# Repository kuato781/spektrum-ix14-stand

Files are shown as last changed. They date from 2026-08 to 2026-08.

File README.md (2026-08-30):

# Adjustable Stand for the Spektrum iX14

A folding, indexed-position desk stand designed for the square carrying handle on the Spektrum iX14 transmitter.

The stand mounts without permanently modifying the radio, folds against the back for storage, and uses a spring-loaded ball plunger with a detent mechanism to provide repeatable viewing positions.

V2 introduces **SMUT™** — **S**ide **M**ount **U**nit **T**echnology: a reusable side-mounted architecture that places independent retained pivots on the individual handle rails instead of relying on a single rear-mounted clamp.

## Which Version Should I Build?

**Build V2 unless you specifically want to reproduce the original prototype.**

| Version | Status | Design | Recommendation |
|---|---|---|---|
| [V2](v2/) | Current design | SMUT™ side-mount assemblies with independent pivots and a replaceable detent ring | **Recommended** — more compact, easier to align, leaves more of the handle open, and is substantially more functional |
| [V1](v1/) | Legacy prototype | CRAP™ rear-mount platform with one external clamp and a common through-bolt pivot | Preserved for reference; development stopped after the concept was proven and moved to V2 |

V1 was successfully printed, assembled, and used as a prototype, but it occupies more handle space, has a taller folded profile, and is less convenient than V2.

It is not the version recommended for a new build.

## Product Photos

Photographs of the actual printed and assembled stands are included with each version:

- [V1 product images](v1/documentation/product-images/) show the original prototype as separate components, assembled, folded, and extended.
- [V2 product images](v2/documentation/product-images/) show the recommended design as separate components, assembled, folded, extended through its usable range, and installed with handle clearance. The V2 collection also includes a direct V1-versus-V2 extension comparison.

These are photographs of physical builds, not CAD renders. For installation order and hardware placement, use the version-specific assembly instructions and printable assembly guide.

## V2 — Recommended SMUT™ Build

V2 is the first physically validated implementation of SMUT™ and includes:

- independent left and right handle-mounted case assemblies;
- self-aligning clamp clearance for radio-to-radio manufacturing variation;
- separate retained pivots that remain free after their hardware is tightened;
- replaceable, keyed detent ring that can be printed as a contrasting wear item;
- square keyed blocks that carry stand shear and twisting loads;
- reinforced heat-set-insert collars;
- directional caps marked `L` and `R`;
- a 110 mm stand with paintable chamfers and editable multicolor text;
- PETG-HF print profiles and tested Bambu Studio plate arrangements.

### Why SMUT™?

**Because rear-entry solutions are unnecessarily restrictive.**

By moving the pivot assemblies to the individual handle rails, SMUT™ preserves full carrying-handle access while providing independent retained pivots, positive indexed positioning, greater range of motion, and a more compact folded profile.

### Start Here

- [V2 assembly instructions](v2/documentation/assembly-instructions/)
- [V2 printable assembly guide](v2/documentation/exploded-view/)
- [V2 Bambu Studio profile](v2/bambu-studio-3mf/)
- [V2 hardware buy list](v2/buy-list/)
- [V2 STL files](v2/stl/)

> **Validation status:** The complete V2 assembly has been physically validated on the radio, including the printed parts, inserts, clamp fit, pivots, stand interface, production M4 × 8 spring-loaded ball plunger, positive detent engagement, full range of motion, folded position, and carrier fit.

## V1 — Legacy CRAP™ Prototype

V1 remains available as the original implementation of **CRAP™** — **C**audal **R**ear **A**nchoring **P**latform — and the project's proof-of-concept design.

Its directory contains the printable models, Bambu Studio project, hardware list, and abbreviated assembly documentation needed to reproduce it.

- [V1 assembly instructions](v1/documentation/assembly-instructions/)
- [V1 printable assembly guide](v1/documentation/exploded-view/)
- [V1 hardware buy list](v1/buy-list/)
- [V1 STL files](v1/stl/)

V1 was prototyped in PLA using largely default Bambu settings.

No further V1 design development is planned; use V2 for the more practical final implementation.

In architectural terms, development moved from CRAP™ to SMUT™.

## AI-Assisted Design and Development

This project was developed with AI assistance.

The stand began with a practical design goal: create a compact, folding stand for the Spektrum iX14 that could mount to the existing square carrying handle without permanently modifying the transmitter.

AI was used throughout the iterative development process to help:

- analyze physical measurements and fitment observations;
- translate design requirements into 3D geometry;
- generate and revise printable models;
- evaluate clearances, interfaces, pivots, detent geometry, and hardware placement;
- create prototype variations based on physical test results;
- organize the versioned design artifacts;
- generate and maintain assembly documentation.

The development process was highly iterative:

**measure → model → print → physically test → revise**

The generated geometry was not assumed to be correct simply because it looked correct in CAD.

Multiple physical prototypes and fitment iterations were used to refine the design, and the repository distinguishes between the original V1 proof-of-concept and the more functional V2 design that resulted from that process.

In other words: AI helped design it, but the printer and the actual radio got the final vote. :-)

## Repository Organization

Each version is self-contained.

| Directory | Contents |
|---|---|
| `stl/` | Individual printable parts |
| `bambu-studio-3mf/` | Ready-to-slice Bambu Studio project and version-specific printing notes |
| `buy-list/` | Version-specific hardware requirements |
| `documentation/assembly-instructions/` | Detailed Markdown assembly instructions |
| `documentation/exploded-view/` | Printable PDF assembly guide and its linked page images |
| `documentation/product-images/` | Photographs of the actual printed parts and completed assembly |

Version-specific dimensions, hardware, slicer settings, and assembly procedures live inside the corresponding version directory so that the root README does not become another stale copy of those details.

## Important Safety Information

- This is a desk and simulator stand, **not a replacement carrying handle**.
- Inspect every print, insert, and fastener before use and periodically afterward.
- Confirm stability before placing the radio on an elevated, uneven, or windy surface.
- Never force the stand beyond its intended range of motion.
- Read the repository [`DISCLAIMER.md`](DISCLAIMER.md) before printing or using the design.

This is an independent project and is not affiliated with or endorsed by Horizon Hobby or Spektrum.

## License

This project is provided under the [Creative Commons Attribution-NonCommercial 4.0 International License](LICENSE).

You may print, copy, share, and modify the files for noncommercial purposes with attribution.

Changes must be identified.

The original files and derivatives may not be sold or otherwise used commercially without separate permission from the creator.

## Why?

Because apparently the natural progression of:

**RC helicopters + 3D printing + AI + excessive iteration**

is spending an unreasonable amount of time designing a stand for a radio that already has a handle.

And that's pretty kewl. :-D

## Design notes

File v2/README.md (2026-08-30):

# Spektrum iX14 Stand — V2 SMUT™ Recommended Design

V2 is the current and recommended stand design and the first physically validated implementation of **SMUT™** — **S**ide **M**ount **U**nit **T**echnology. Its two compact assemblies mount around the individual handle rails, preserving more usable handle space while providing independent retained pivots and a replaceable keyed detent ring.

## Why SMUT™?

**Because rear-entry solutions are unnecessarily restrictive.**

SMUT™ moves the stand pivots from a single rear-mounted clamp to purpose-designed side-mount assemblies. The result preserves full carrying-handle access while providing positive indexed positioning, greater range of motion, straightforward left-to-right alignment, and a more compact folded profile.

## Product Images

The [V2 product-images directory](documentation/product-images/) contains photographs of the actual printed and assembled design:

- a direct V1-versus-V2 extension comparison (`00-v1-vs-v2-range.jpg`);
- separate printed components;
- completed assembly;
- folded position;
- normal and maximum extended positions;
- side views showing the increased range of motion;
- remaining carrying-handle clearance.

These photographs document the physical build and its usable positions; they are not CAD renders or assembly diagrams.

## Version Contents

- [STL files](stl/)
- [Bambu Studio project and tested PETG-HF profile](bambu-studio-3mf/)
- [Hardware buy list](buy-list/)
- [Assembly instructions](documentation/assembly-instructions/)
- [Printable assembly guide](documentation/exploded-view/)

The complete V2 assembly has been physically validated on the radio, including the printed parts, inserts, clamp fit, pivots, stand interface, production M4 × 8 spring-loaded ball plunger, positive detent engagement, full range of motion, folded position, and carrier fit.

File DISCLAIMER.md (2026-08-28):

# Use at Your Own Risk

The design files, models, print profiles, instructions, photographs and other materials in this repository are provided for personal, noncommercial use on an **as-is** and **as-available** basis.

## No warranty

No warranty or representation is made that the materials are accurate, complete, error-free, safe, suitable for a particular purpose or compatible with any specific printer, material, tool, device or application.

3D-printed parts can vary significantly because of printer calibration, filament condition, material selection, slicer settings, print orientation, layer adhesion, environmental exposure, assembly technique, hardware tolerances and normal wear.

## Your responsibility

You are solely responsible for determining whether a design is suitable for your intended use. Before relying on any printed part or procedure, you should:

- Review the design, dimensions, hardware and instructions.
- Confirm that your printer, material and slicer settings are appropriate.
- Inspect every print for cracks, poor layer adhesion, deformation or other defects.
- Verify the fit, alignment, fasteners, inserts and range of motion during assembly.
- Test the completed item in a controlled and safe environment.
- Reinspect printed parts and hardware periodically and replace anything damaged, loose or worn.
- Independently verify any measurements, alignments, control settings or mechanical adjustments that could affect equipment operation or safety.

Do not assume that a successful print or another user's successful result guarantees that your copy will perform the same way.

## Assumption of risk

By downloading, printing, modifying, assembling or using these materials, you accept all associated risks. These may include failed prints, damaged filament or tools, ruined project materials, damage to equipment or property, loss of use and personal injury.

These materials are not professionally engineered, certified or tested as safety equipment. Do not use them for life-support, fall-protection, structural, load-bearing, emergency or other safety-critical applications.

## Limitation of liability

To the maximum extent permitted by applicable law, the creator and contributors will not be liable for any direct, indirect, incidental, special, consequential, exemplary or other loss, damage, cost or injury arising from the materials or their use, modification, assembly or inability to be used.

## Modifications and redistribution

If you modify or redistribute these materials, clearly identify your changes. You are responsible for validating your modified version and should preserve this disclaimer or provide an equivalent notice to downstream users.

## Relationship to the license

This disclaimer supplements the repository's [`LICENSE`](LICENSE) file and does not replace or modify its terms. If there is any conflict, the license controls.

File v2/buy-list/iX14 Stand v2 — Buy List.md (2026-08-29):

# iX14 Stand v2 — Buy List

### Heated inserts
- [ ] **6 × M3 heat-set inserts**, approximately **5 mm OD × 5 mm long** 
- [ ] **1 × M4 heat-set insert**, approximately **6 mm OD × 6 mm long** 
### Ball plunger
- [ ] **1 × M4 × 0.7 spring-loaded ball plunger**
  - Approximately **8–9 mm overall threaded-body length**
  - Approximately **2.5 mm ball**
  - Tested hardware elastic range: **3–15 N**
  - Available at Lowes: <a href="https://www.lowes.com/pd/Unique-Bargains-Ball-Point-Set-Screws-M4-x-8mm-304-Stainless-Steel-Metric-Spring-Hex-Socket-Screw-20pcs/6374188" target="_blank" rel="noopener noreferrer">M4 x 8mm Spring Hex Socket Screw</a> *(Ctrl+Click or Cmd+Click to open in a new tab)*
## Bolts, washers, nuts
- [ ] **2 × M4 × 20 mm socket-head or button-head screws**
- [ ] **2 × M4 nyloc nut**
- [ ] **2 × M4 flat washers**
- [ ] **4 × M3 × 12 mm socket-head or button-head screws**
- [ ] **2 × M3 × 8 mm socket-head or button-head screws**
- [ ] **2 × M3 flat washers**

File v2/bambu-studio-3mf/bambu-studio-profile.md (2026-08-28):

# Bambu Studio Profile — iX14 Stand V2

The supplied Bambu Studio project contains all eight V2 printed parts arranged across four plates:

[`../bambu-studio-3mf/ix14_v2_stand_all_objects.3mf`](../bambu-studio-3mf/ix14_v2_stand_all_objects.3mf)

The project was prepared on a Bambu Lab H2C with an AMS HT and two AMS 2 Pro units. It may be adapted to another compatible Bambu printer, but always confirm the printer, plate, nozzle and filament assignments before slicing.

## Recommended material

- Bambu PETG-HF for all structural parts
- Dry PETG-HF at 65 °C for eight hours before printing
- Use the built-in **Bambu PETG HF** filament preset
- Textured PEI build plate

## Global process settings

Start with **0.20 mm Standard** and change only the following:

- 0.4 mm standard nozzle
- 5 wall loops
- 5 top shell layers
- 5 bottom shell layers
- 25% gyroid infill
- Standard speed
- No scaling or XY/hole compensation
- No ironing

## Four-plate project

| Plate | Contents | Notes |
| ---: | --- | --- |
| 1 | Both case bodies, both caps and both pivot stubs | Structural parts with per-object supports and the saved Auto brim setting |
| 2 | Replaceable detent ring | Print the detent pockets against the build plate |
| 3 | Single-color stand | No supports or brim |
| 4 | Multicolor stand with editable `LAWN-DART` text | Verify filament mapping, painted chamfers and text before slicing |

Only the filament slots used by the selected plate matter. The stored project uses Bambu PETG-HF for the active objects; unused AMS slots may still display other materials. Remap every active object to the intended PETG-HF spool before printing.

## Per-object settings

| Part | Orientation | Supports | Brim |
| --- | --- | --- | --- |
| Left and right case bodies | Supplied STL orientation | Tree (Auto), default style, build plate only | Auto brim, 5 mm width |
| Right detent pivot stub | Supplied STL orientation | Tree (Auto), default style, build plate only | Auto brim, 5 mm width |
| Left plain pivot stub | Lay on its side as arranged in the 3MF | Tree (Auto), default style, build plate only | Auto brim, 5 mm width |
| Left and right caps | Flip 180° so the joiner/mating face is on the build plate | None | Saved Auto setting; no manual brim required |
| Replaceable detent ring | Flat with detent pockets downward | None | None |
| Stand | Flat with sockets upward; rotate 90° on the build plate for improved torsional layer orientation | None | None |

> **Validated Plate 1 brim setting:** the global **Auto brim / 5 mm** setting stored in the 3MF completed a successful physical print of the full plate. Leave this setting as saved; no per-object 8 mm override is required.

## Multicolor stand

Plate 4 contains the paintable stand and an editable Bambu Studio text object.

1. Assign the stand body to the primary PETG-HF color.
2. Use the paint-bucket tool to fill the continuous chamfer faces with the accent color.
3. Edit or remove the `LAWN-DART` text as desired.
4. Assign the text to the accent-color PETG-HF spool.
5. Slice and inspect Preview to confirm that every intended chamfer and letter changes color cleanly.

Suggested color combinations:

- Deadpool: black body with red chamfers, text and detent ring
- Wolverine: black body with yellow chamfers, text and detent ring

## Pre-print checklist

- PETG-HF completed an eight-hour drying cycle
- Correct printer and textured PEI plate selected
- 0.4 mm nozzle selected
- Every active object mapped to PETG-HF
- Plate 1 retains the validated Auto brim / 5 mm setting
- Supports are build-plate-only on the four supported objects
- Detent ring pockets face downward
- Caps have their mating faces on the plate
- Stand sockets face upward
- Painted stand preview shows the intended colors
- First layers observed before leaving the printer unattended

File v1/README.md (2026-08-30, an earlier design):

# Spektrum iX14 Stand — V1 Legacy CRAP™ Prototype

V1 is the original implementation of **CRAP™** — **C**audal **R**ear **A**nchoring **P**latform — and the project's proof-of-concept stand. It was successfully printed, assembled, and used to validate the folding detent concept, but development moved to the more compact and functional [V2 SMUT™ design](../v2/).

Build V1 only if you specifically want to reproduce the original prototype. For a new stand, V2 is recommended.

## Product Images

The [V1 product-images directory](documentation/product-images/) contains photographs of the actual printed prototype:

- separate printed components;
- completed assembly;
- folded position;
- extended position;
- extended side view.

These photographs document the physical build and its usable positions; they are not CAD renders or assembly diagrams.

## Version Contents

- [STL files](stl/)
- [Bambu Studio project](bambu-studio-3mf/)
- [Hardware buy list](buy-list/)
- [Assembly instructions](documentation/assembly-instructions/)
- [Printable assembly guide](documentation/exploded-view/)

V1 was prototyped in PLA using largely default Bambu Studio settings. Its complete folding and indexed-detent mechanism has been physically validated with the production M4 × 8 spring-loaded ball plunger. No further V1 design development is planned.

In architectural terms, development moved from CRAP™ to SMUT™.

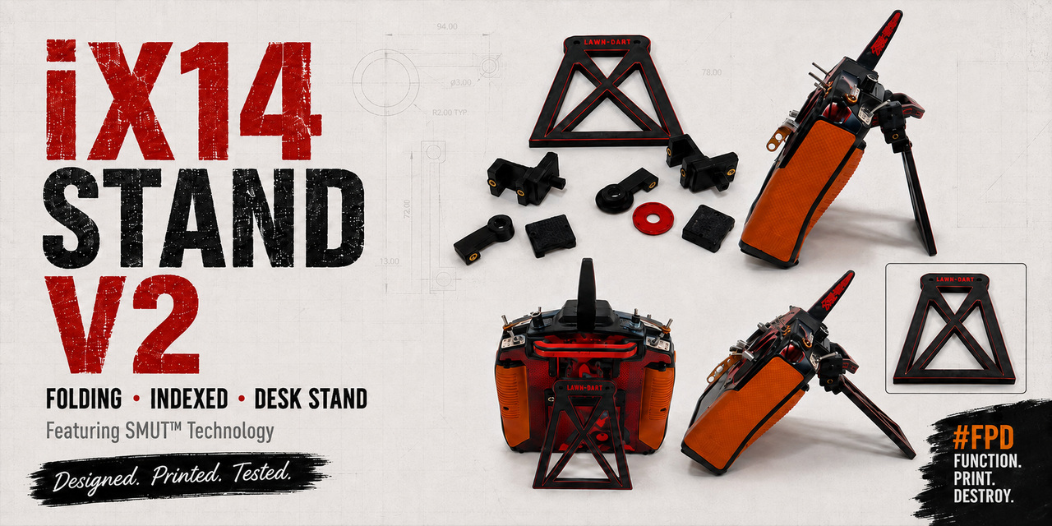
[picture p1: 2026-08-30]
ix14_stand_github_social_1280x640.jpg

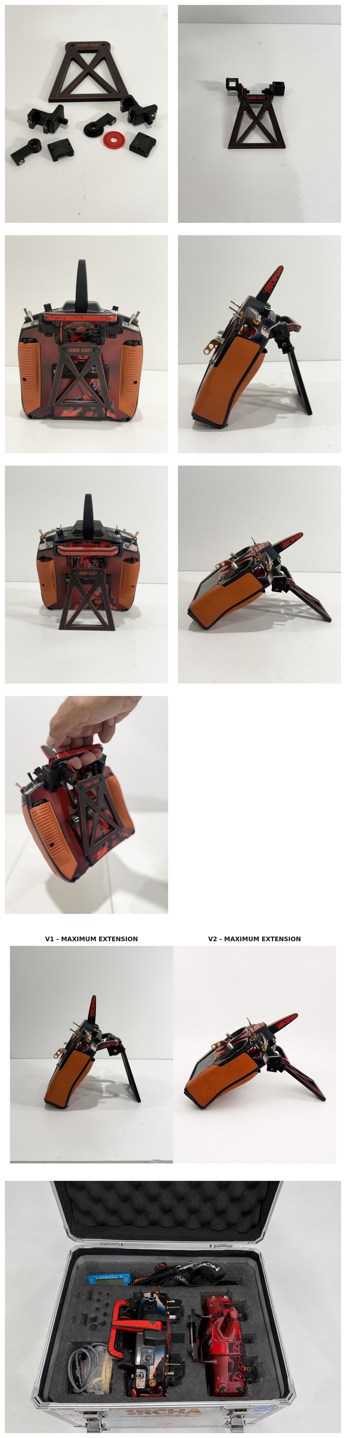
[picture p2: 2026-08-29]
v2/documentation/product-images/00-v2-contact-sheet.jpg

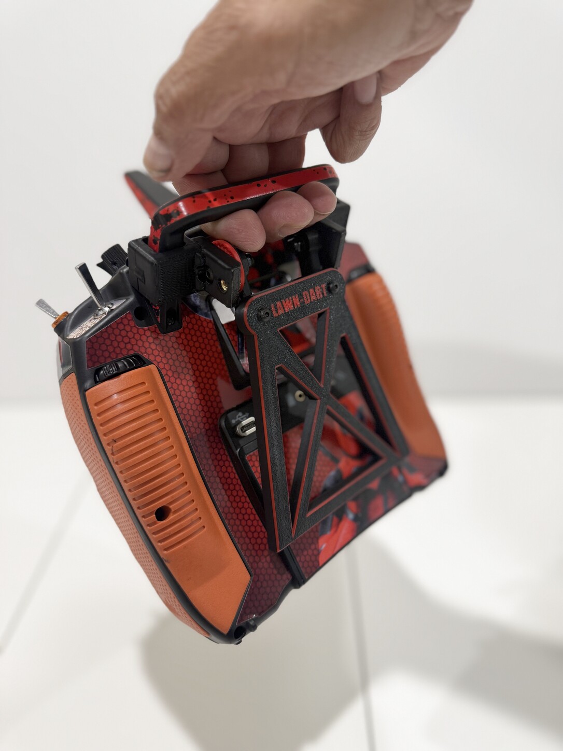
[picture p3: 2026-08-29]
v2/documentation/product-images/08-v2_clearance.jpg

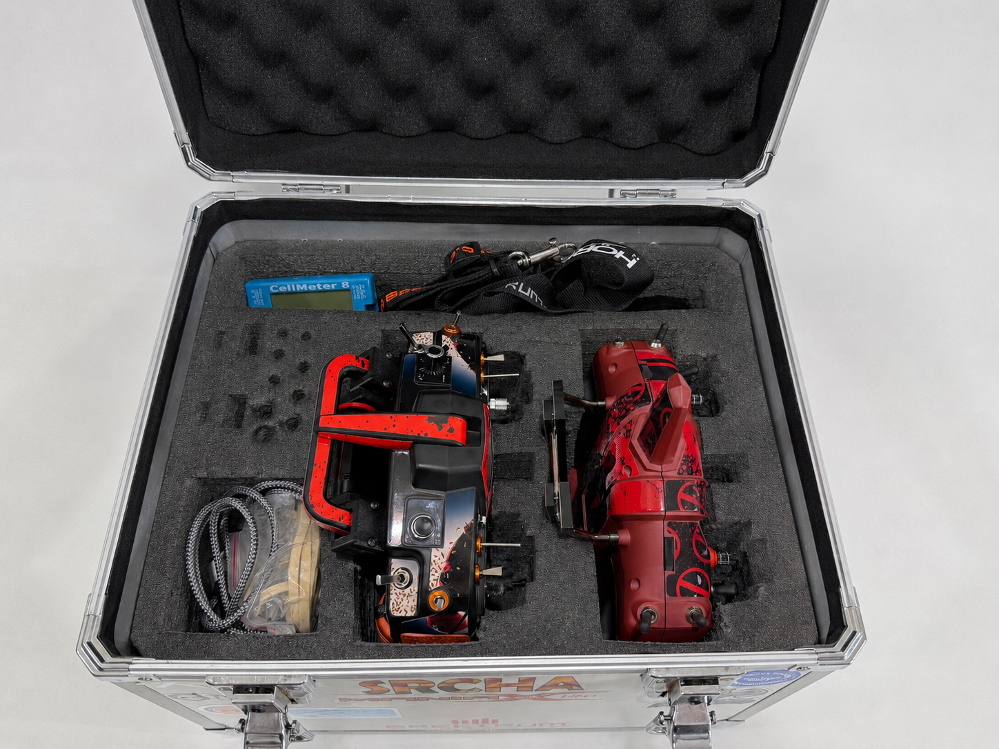
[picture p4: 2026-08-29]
v2/documentation/product-images/10-v2-carrier-fit.jpg

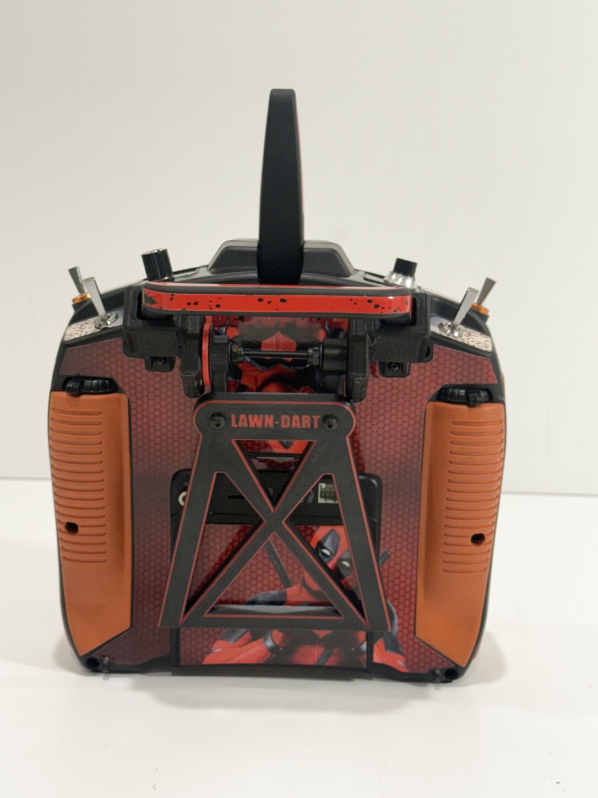
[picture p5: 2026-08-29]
v2/documentation/product-images/03-v2_folded.jpg

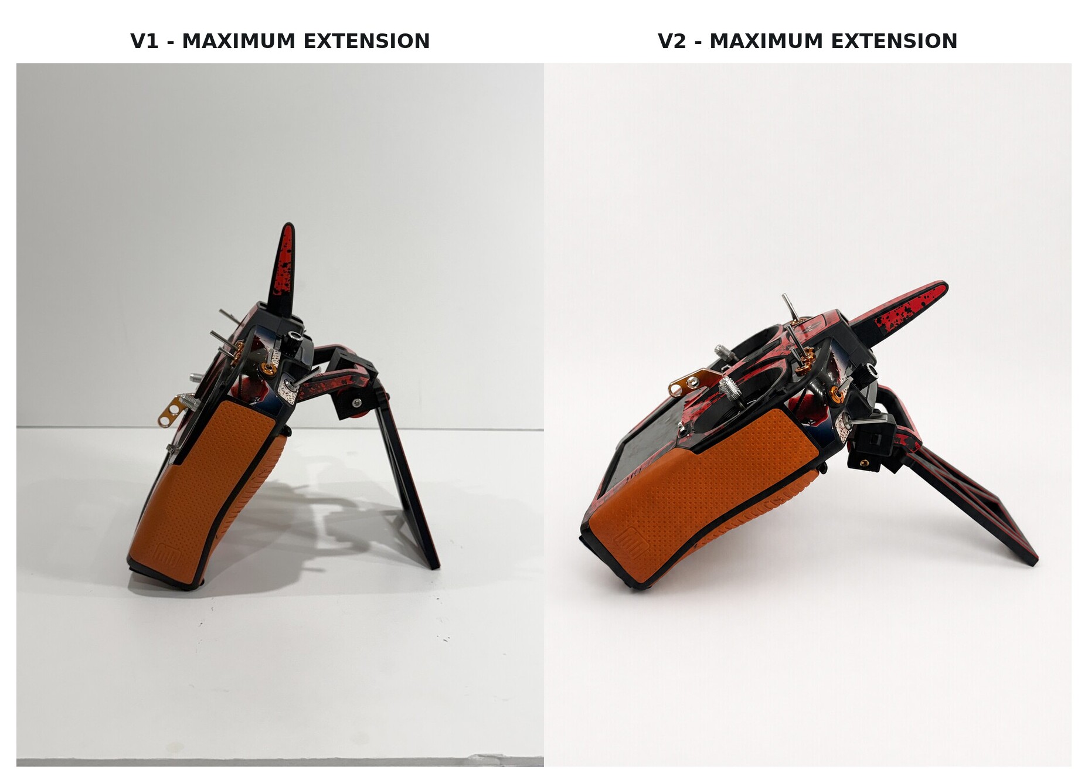
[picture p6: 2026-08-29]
v2/documentation/product-images/09-v1-vs-v2-range.jpg

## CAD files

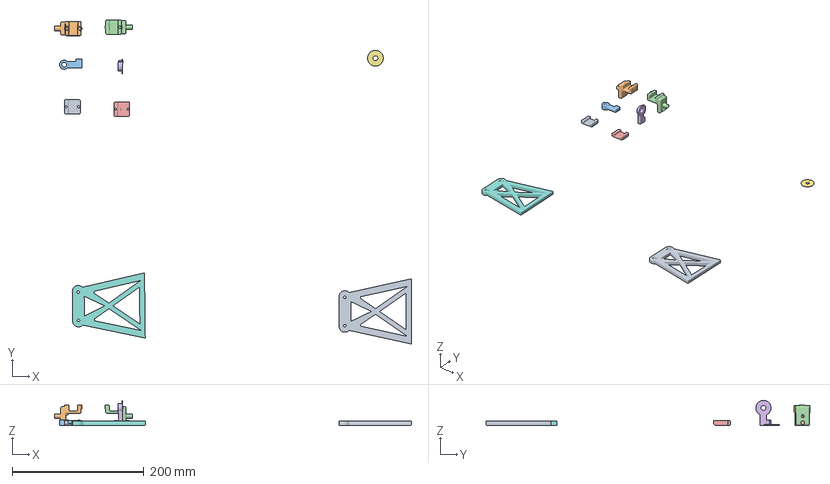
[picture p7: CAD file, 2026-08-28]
v2/bambu-studio-3mf/ix14_v2_stand_all_objects.3mf
541.7 x 491.7 x 38.5 mm
ix14_v2_left_case_cap.stl
ix14_v2_left_plain_case_body.stl
ix14_v2_left_plain_pivot_stub.stl
ix14_v2_right_detent_case_body.stl
ix14_v2_right_case_cap.stl
ix14_v2_right_detent_pivot_stub.stl
ix14_v2_replaceable_detent_ring.stl
ix14_v2_stand.stl
ix14_v2_stand_colored.stl

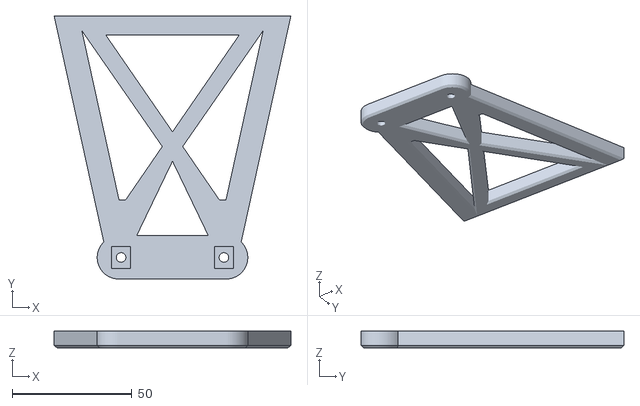
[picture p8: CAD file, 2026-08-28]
v2/stl/ix14_v2_stand.stl
99.0 x 110.0 x 7.00

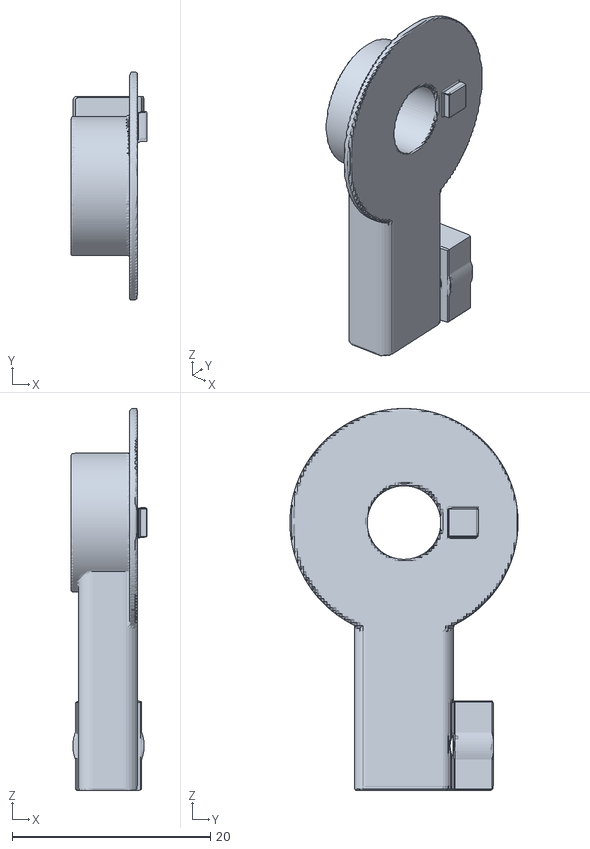
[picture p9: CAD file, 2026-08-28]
v2/stl/ix14_v2_right_detent_pivot_stub.stl
7.70 x 23.0 x 38.5

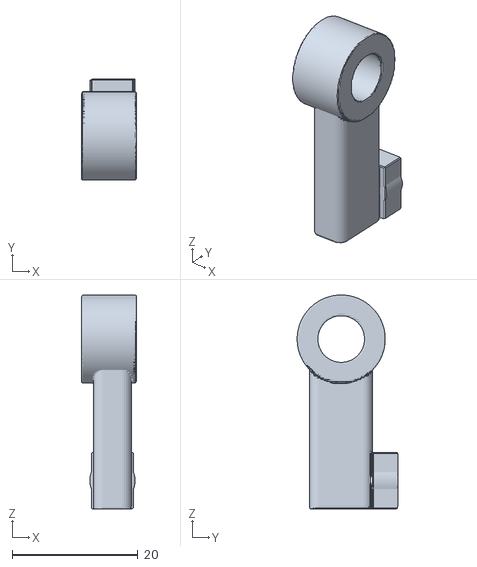
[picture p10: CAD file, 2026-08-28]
v2/stl/ix14_v2_left_plain_pivot_stub.stl
8.70 x 16.0 x 34.0

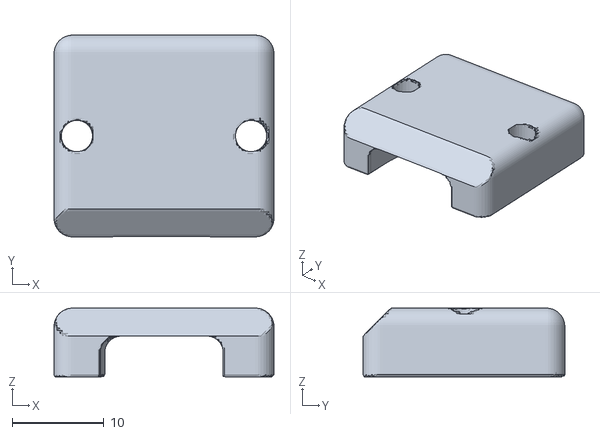
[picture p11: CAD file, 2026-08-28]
v2/stl/ix14_v2_left_case_cap.stl
24.0 x 22.0 x 7.50

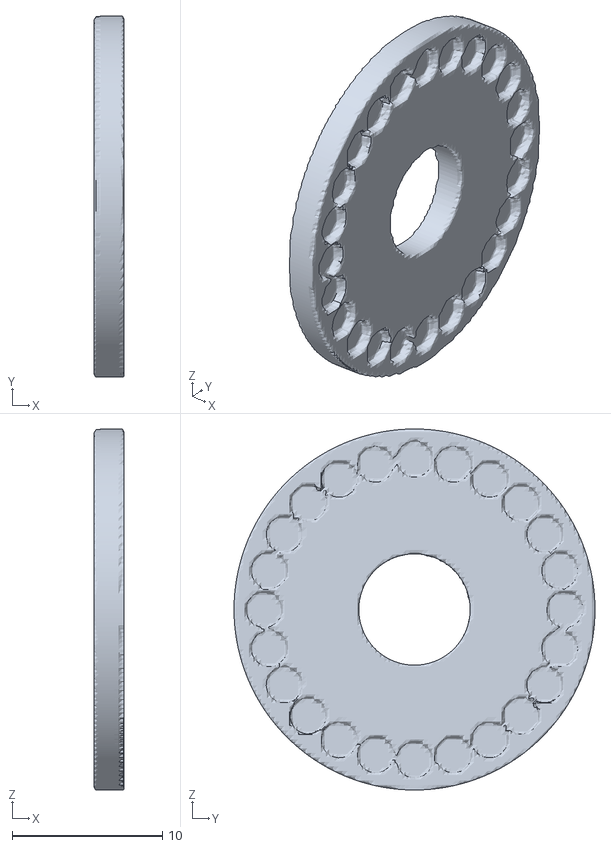
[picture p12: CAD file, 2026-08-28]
v2/stl/ix14_v2_replaceable_detent_ring.stl
2.00 x 24.0 x 24.0

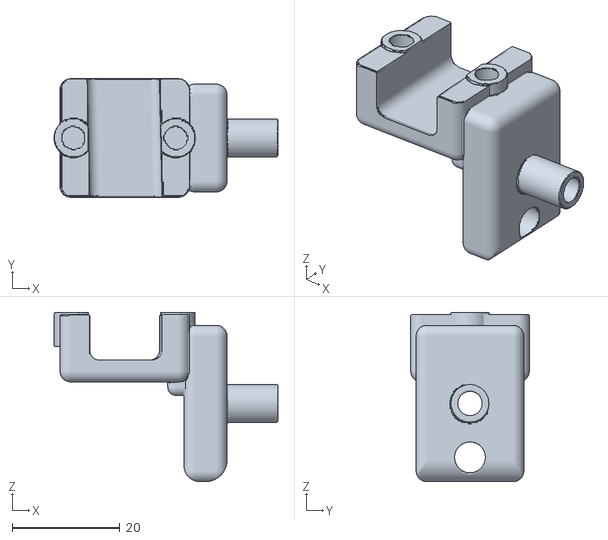
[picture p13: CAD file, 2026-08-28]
v2/stl/ix14_v2_right_detent_case_body.stl
41.5 x 22.0 x 31.4

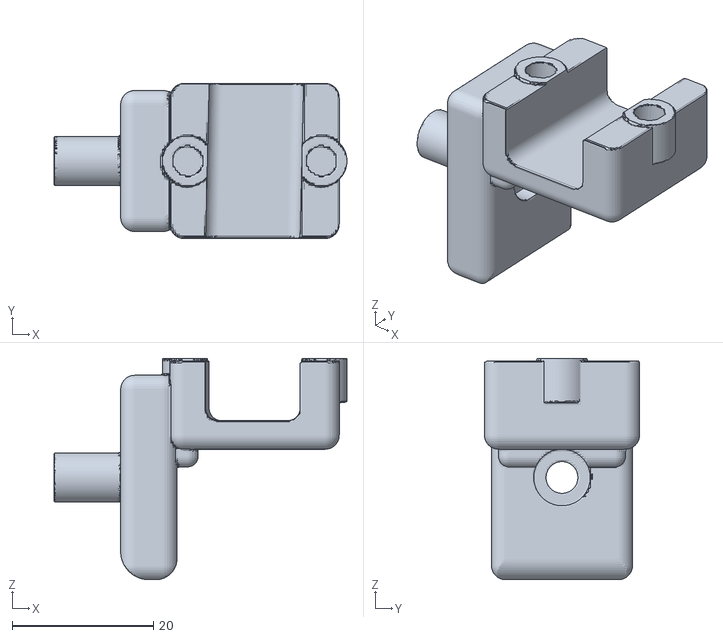
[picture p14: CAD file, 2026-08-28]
v2/stl/ix14_v2_left_plain_case_body.stl
41.5 x 22.0 x 31.4

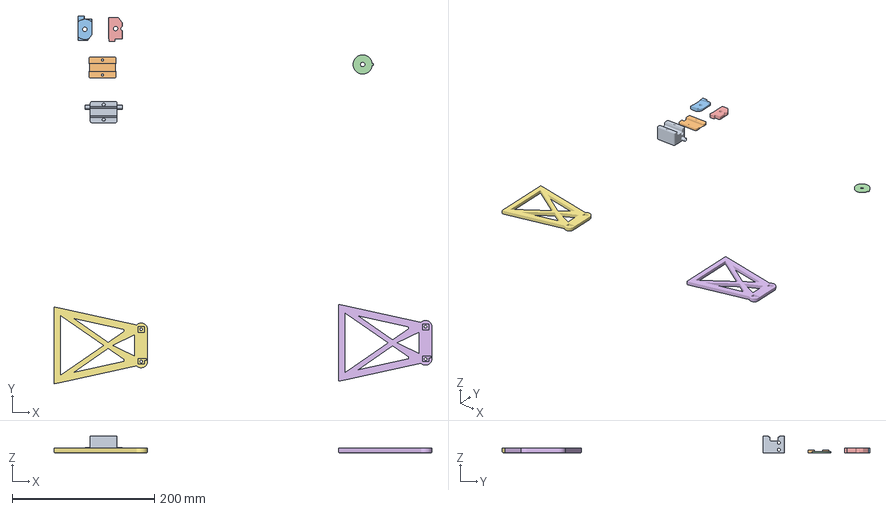
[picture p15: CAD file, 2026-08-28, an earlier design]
v1/bambu-studio-3mf/ix14_v1_stand_all_objects.3mf
531.1 x 516.6 x 23.5 mm
ix14_v1_clamp_body.stl
ix14_v1_clamp_cap.stl
ix14_v1_right_detent_ear.stl
ix14_v1_detent.stl
ix14_v1_left_ear.stl
ix14stand_v1.stl x 2

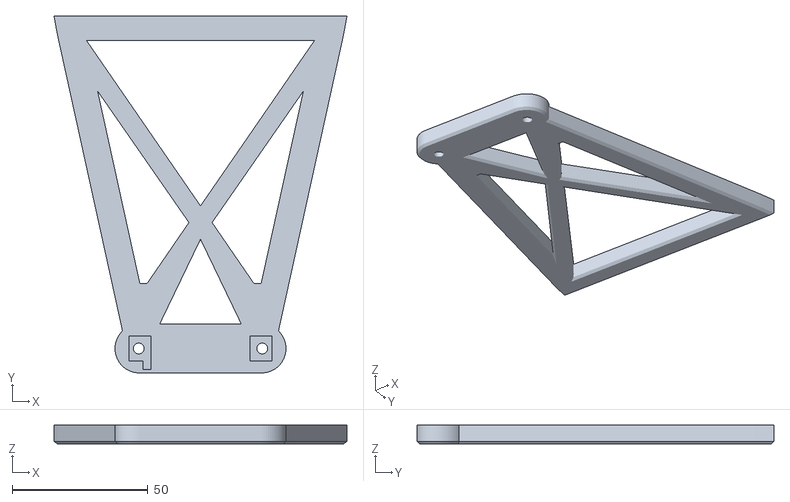
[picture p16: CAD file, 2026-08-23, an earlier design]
v1/stl/ix14_v1_stand.stl
107.9 x 131.5 x 7.00

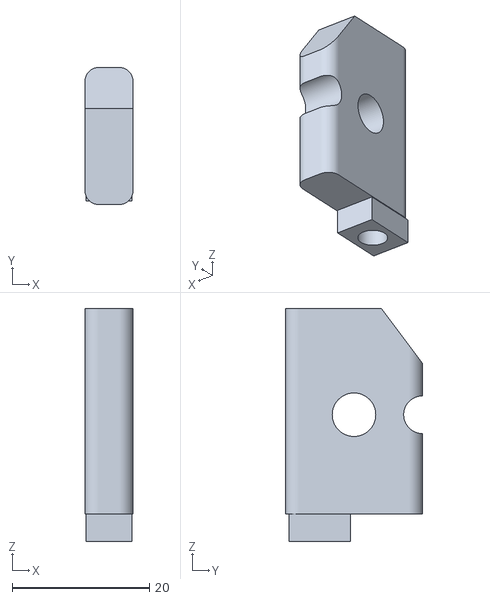
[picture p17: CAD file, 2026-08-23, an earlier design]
v1/stl/ix14_v1_left_ear.stl
7.00 x 20.0 x 34.0

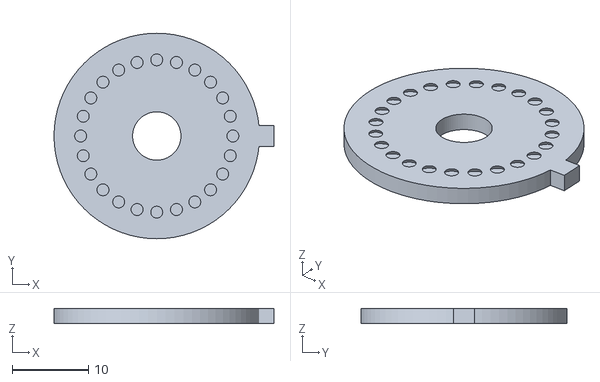
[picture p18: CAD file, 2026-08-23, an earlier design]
v1/stl/ix14_v1_detent.stl
28.9 x 27.0 x 2.00

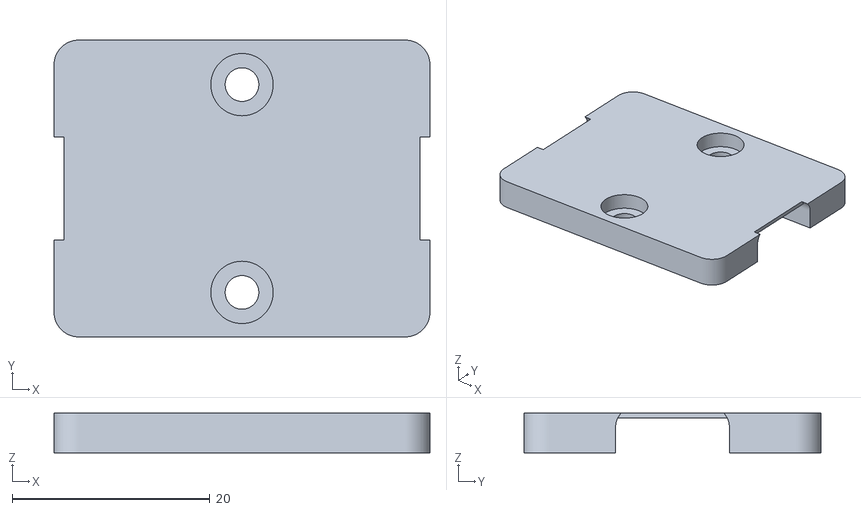
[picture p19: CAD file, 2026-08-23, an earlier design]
v1/stl/ix14_v1_clamp_cap.stl
38.0 x 30.0 x 4.00

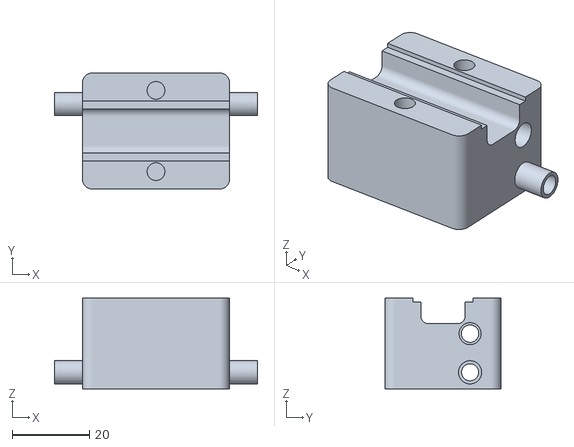
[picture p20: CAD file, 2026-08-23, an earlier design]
v1/stl/ix14_v1_clamp_body.stl
52.5 x 30.0 x 23.5

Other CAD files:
v2/stl/ix14_v2_right_case_cap.stl
v1/stl/ix14_v1_right_detent_ear.stl

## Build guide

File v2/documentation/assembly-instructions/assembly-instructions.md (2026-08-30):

# Assembly Instructions — iX14 Stand V2 SMUT™ System

[Download the printable three-stage assembly guide (PDF)](../exploded-view/ix14-v2-assembly-guide.pdf)

These instructions apply to the V2 implementation of **SMUT™** — **S**ide **M**ount **U**nit **T**echnology. Its independent left and right assemblies mount around the individual handle rails. **Left and right are always described while looking at the front of the radio.**

> **Hardware status:** the complete mechanism has been physically validated on the radio with the production M4 × 8 spring-loaded ball plunger. The plunger provides positive engagement at each indexed stand position while preserving smooth movement through the full range of motion.

## Printed parts

| Quantity | Part |
| ---: | --- |
| 1 | Left plain case body |
| 1 | Left cap, marked `L` underneath |
| 1 | Left plain pivot stub |
| 1 | Right detent case body |
| 1 | Right cap, marked `R` underneath |
| 1 | Right detent pivot stub |
| 1 | Replaceable detent ring |
| 1 | 110 mm stand |

Use the [V2 buy list](<../../buy-list/iX14 Stand v2 — Buy List.md>) for the complete hardware list.

## Insert locations

Install all heat-set inserts before mounting the cases to the radio.

- **4 × M3 inserts:** two reinforced cap-screw pockets in each case body
- **2 × M3 inserts:** one square stand-mounting block on each pivot stub
- **1 × M4 insert:** spring-plunger bore in the right detent case body

Use the alignment feature supplied with your heat-set tool, such as an insert-centering nub, whenever one is available. If your heat-set setup does not already provide an alignment solution, an appropriate screw may be threaded loosely into the insert to help keep it straight. Press the insert into its reinforced collar and allow the part to cool completely before applying load.

[Stage 1: build the left and right pivot assemblies](../exploded-view/images/step-1.png)

## 1. Assemble the right detent pivot

1. Place the replaceable detent ring on the support face of the right detent pivot stub.
2. Align the asymmetric square key and recess. The ring should seat fully without force.
3. Orient the detent pockets toward the right case body and its ball-plunger bore.
4. Slide the right pivot stub over the case body's 7 mm pivot sleeve.
5. Install the M4 pivot bolt through the case body, sleeve and stub.
6. Fit the M4 washer on the Nyloc side, then install the M4 Nyloc nut.
7. Tighten until the hardware is firmly seated. Confirm that the sleeve shoulder prevents the stub from being pinched and that the stub still rotates freely.

## 2. Assemble the left plain pivot

1. Slide the left plain pivot stub over the left case body's pivot sleeve.
2. Install the M4 pivot bolt through the case body, sleeve and stub.
3. Fit the M4 washer on the Nyloc side, then install the M4 Nyloc nut.
4. Tighten until firmly seated and confirm smooth, free rotation.

## 3. Mount the case assemblies to the handle

[Stage 2: attach the case assemblies to the radio handle](../exploded-view/images/step-2.png)

1. Place the completed left and right assemblies around their corresponding iX14 handle rails.
2. Match the cap marked `L` to the left body and the cap marked `R` to the right body.
3. Install two M3 × 12 screws through each cap.
4. Tighten the four cap screws only enough to hold the assemblies in place. Leave enough movement for the stand to square and align both sides.

Washers are not required under the case-cap screws.

## 4. Attach the stand

[Stage 3: attach, square and tighten the stand](../exploded-view/images/step-3.png)

1. Align the stand's two rectangular sockets with the square mounting blocks on the pivot stubs.
2. Seat both blocks completely in the stand sockets.
3. Install one M3 × 8 screw and M3 washer through each stand hole and into the insert in the corresponding stub block.
4. Leave both stand screws slightly loose during alignment.

The square blocks carry the stand's shear and twisting loads; the M3 screws retain and clamp the keyed connection.

## 5. Square and tighten the assembly

1. Push both handle-mounted case assemblies as far toward the radio body as they will naturally seat.
2. Use the attached stand to bring both pivot assemblies square and parallel.
3. Tighten the four M3 × 12 cap screws evenly, alternating between screws so each cap clamps uniformly.
4. Tighten the two M3 × 8 stand screws and washers.
5. Fold and deploy the stand through its complete travel to confirm that neither side binds or shifts.

Do not overtighten the cap screws against the radio handle.

## 6. Install and adjust the ball plunger

1. Use something thin, such as an awl or straightened paper clip, to place a **small amount of removable, non-permanent threadlocker** (for example, blue Loctite) inside the receiving threads of the M4 insert. Keep the threadlocker off the surrounding plastic and out of the plunger mechanism.
2. Insert the M4 × 8 spring-loaded ball plunger **ball end first** through the access bore, then thread it into the M4 insert in the right detent case body.
3. Advance the plunger a little at a time while repeatedly moving the stand between its fully folded and fully extended positions.
4. Continue making small adjustments until the ball engages the detent recesses solidly at each indexed position without making the pivot overly tight or difficult to move.
5. Cycle the stand repeatedly through its full range. Confirm positive engagement at every position and verify that the replaceable detent ring remains fully seated.

The correct setting is the point at which the detents feel deliberate and secure while the stand still moves smoothly. Do not use permanent threadlocker.

## Final inspection

- Both case assemblies are fully seated toward the radio body
- Left and right caps are correctly matched
- All four cap screws are evenly tightened
- Both pivot bolts are secure with washers and Nyloc nuts
- Both pivots rotate freely without axial looseness
- Detent ring key is fully seated and pockets face the plunger
- Ball plunger engages each detent recess positively without binding
- Stand blocks are fully seated in both sockets
- Both stand screws have washers and are secure
- Stand deploys smoothly and supports the radio at the intended angle
- Stand folds without contacting the radio body, switches or controls
- Handle opening remains clear for normal carrying

## Safety and maintenance

- This is a desk/simulator stand, not a replacement carrying handle.
- Inspect the printed parts, inserts and fasteners periodically for cracks, loosening or wear.
- Replace the detent ring if its pockets become rounded or inconsistent.
- Recheck cap and stand screws after the first several use cycles.
- Recheck the ball-plunger adjustment after the first several use cycles and whenever engagement begins to feel weak or excessively tight.
- Never force the stand beyond its designed range of motion.
- Use the stand at your own risk and verify stability before placing the radio on any elevated, uneven or windy surface.

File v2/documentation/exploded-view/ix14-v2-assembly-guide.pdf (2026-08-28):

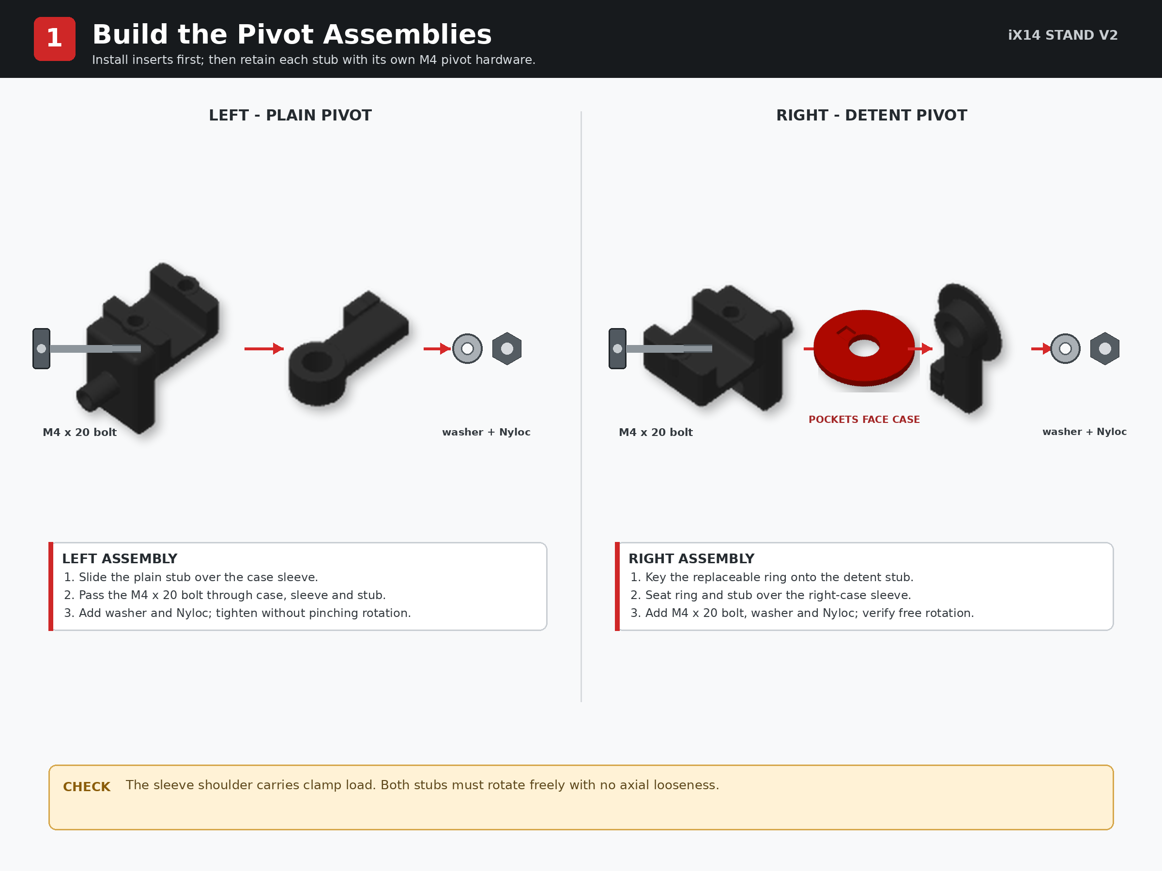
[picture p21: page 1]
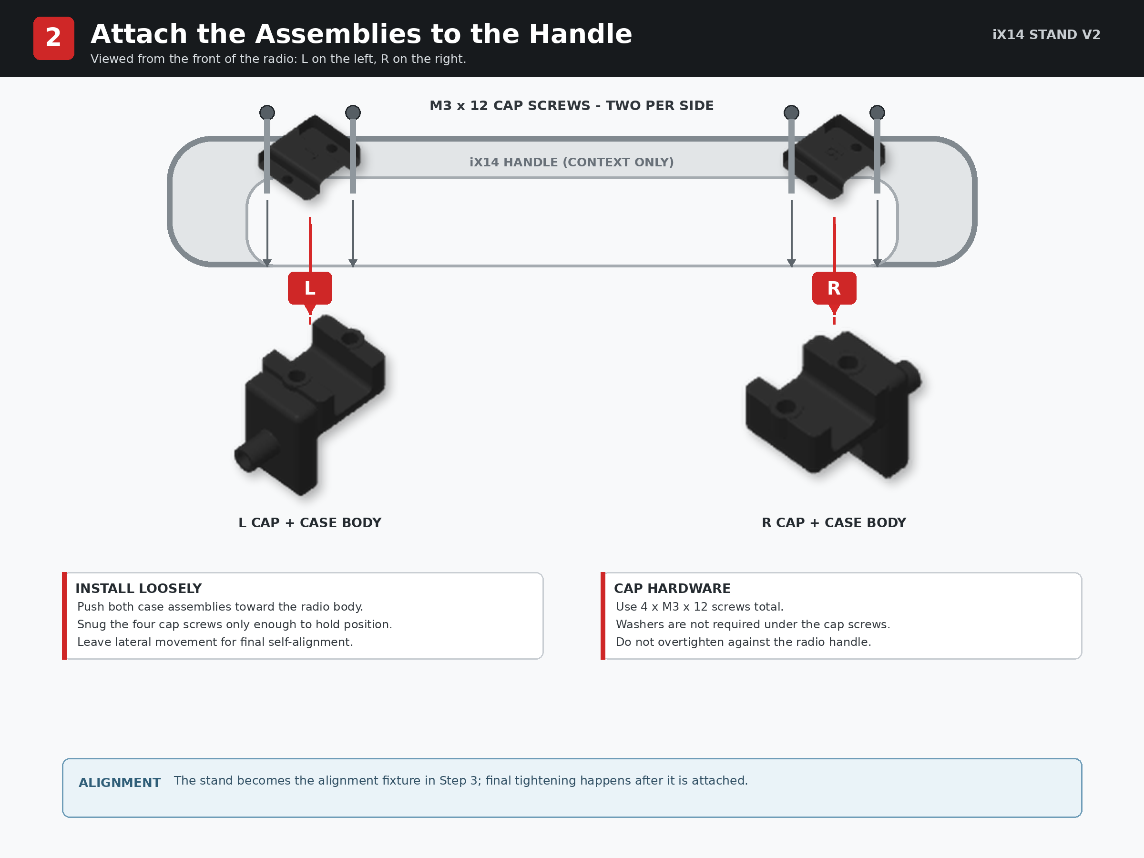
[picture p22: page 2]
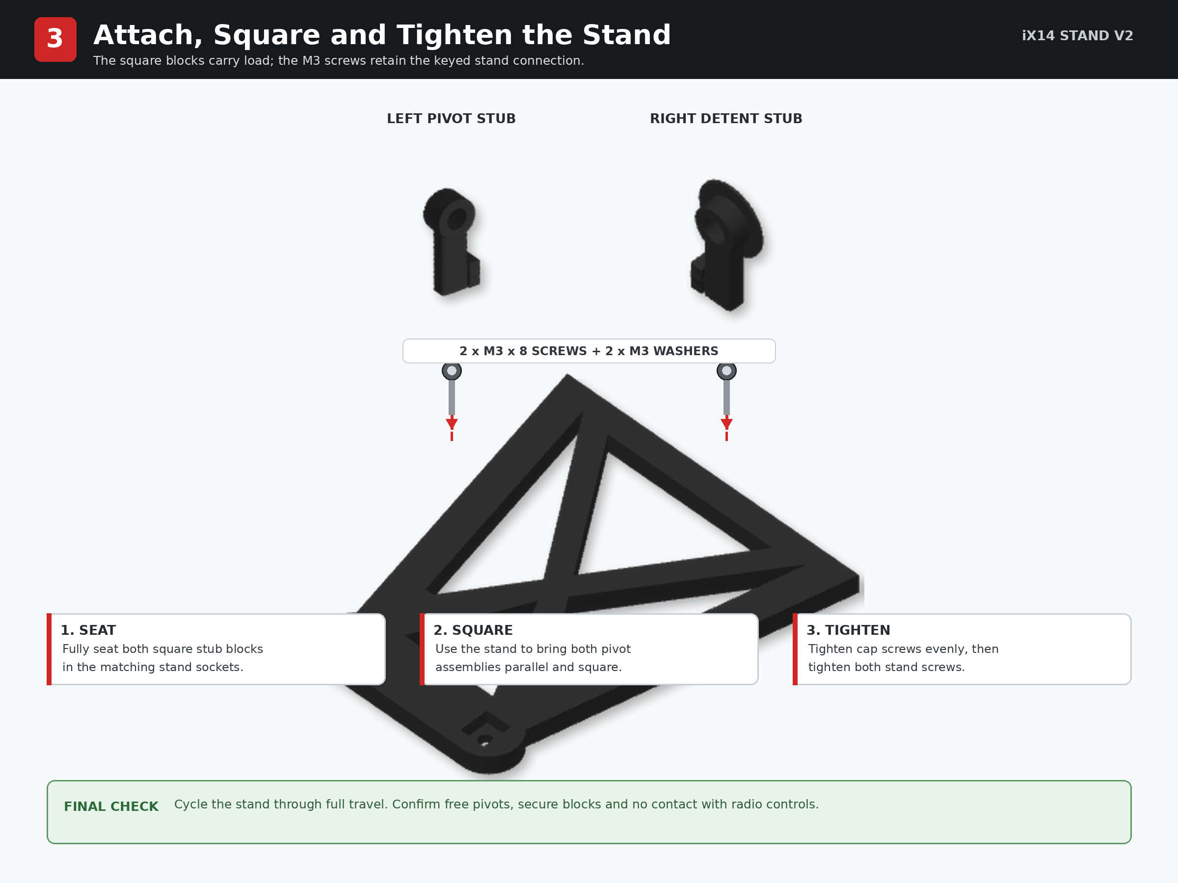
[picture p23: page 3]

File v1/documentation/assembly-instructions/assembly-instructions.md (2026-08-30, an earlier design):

# Assembly Instructions - iX14 Stand V1 CRAP™ System

[Download the printable two-stage assembly guide (PDF)](../exploded-view/ix14-v1-assembly-guide.pdf)

V1 is the original external-handle implementation of **CRAP™** — **C**audal **R**ear **A**nchoring **P**latform. It was physically fit-tested and used successfully in PLA, but development moved to the V2 SMUT™ system because V2 is easier to install, more compact, more adjustable and leaves more of the carrying handle open. **New builders should use V2 unless they specifically want to reproduce the original design.**

> **Hardware status:** the complete V1 mechanism has been physically validated with the production M4 x 8 spring-loaded ball plunger, including positive detent engagement, smooth movement through the full range of motion, and the folded position.

## Printed parts

| Quantity | Part |
| ---: | --- |
| 1 | Clamp body |
| 1 | Clamp cap |
| 1 | Left ear with ball-plunger access relief |
| 1 | Right detent ear |
| 1 | Keyed detent disk |
| 1 | Stand |

Use the [V1 buy list](<../../buy-list/iX14 Stand v1 — Buy List.md>) for the complete hardware list. The physically verified common pivot bolt is **M4 x 60 mm**; a 65 mm bolt is unnecessarily long.

## Printing notes

V1 was prototyped in PLA using the supplied Bambu Studio project and largely default Bambu PLA Basic / 0.20 mm Standard settings. The project contains four plates: the clamp and ears, detent disk, single-color stand and multicolor stand.

- Use a 0.4 mm nozzle and 0.20 mm layer height.
- Use the supplied 3MF orientations and inspect the sliced preview before printing.
- Do not scale any part.
- Confirm supports, brim, printer, plate and filament assignments for your machine.
- Inspect all parts for weak layers, cracks or malformed holes before assembly.

## Insert locations

Install all heat-set inserts before mounting anything to the radio.

- **2 x M3 inserts:** the two cap-screw pockets in the clamp body
- **2 x M3 inserts:** one stand-mounting pocket in each ear
- **1 x M4 insert:** the ball-plunger bore in the clamp body

Use the alignment feature supplied with your heat-set tool whenever one is available. If your setup does not provide an alignment solution, an appropriate screw may be threaded loosely into the insert to help keep it straight. Allow each part to cool completely before applying load.

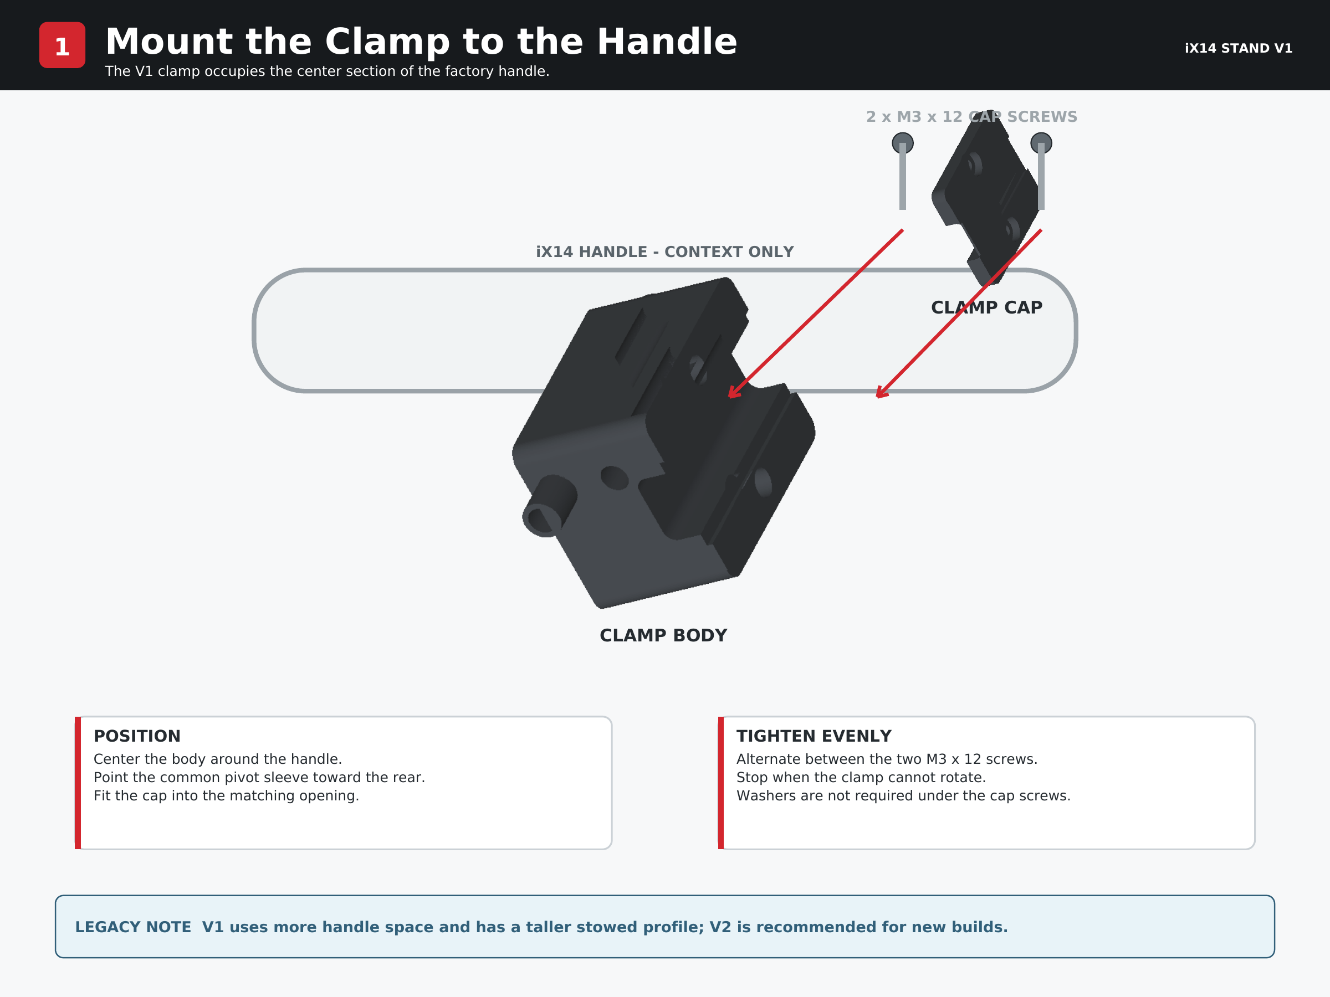
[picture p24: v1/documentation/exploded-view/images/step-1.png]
Stage 1: mount the clamp around the radio handle


## 1. Mount the clamp to the handle

1. Position the clamp body around the center section of the iX14 handle with the pivot sleeve facing the rear of the radio.
2. Fit the clamp cap into the matching body opening.
3. Install two M3 x 12 screws through the cap and into the M3 inserts in the clamp body.
4. Tighten the screws evenly, alternating between them so the cap seats uniformly.
5. Stop when the clamp is secure and cannot rotate on the handle.

Washers are not required under the clamp-cap screws. Do not overtighten the clamp against the radio handle.

## 2. Assemble the stand and install the common pivot

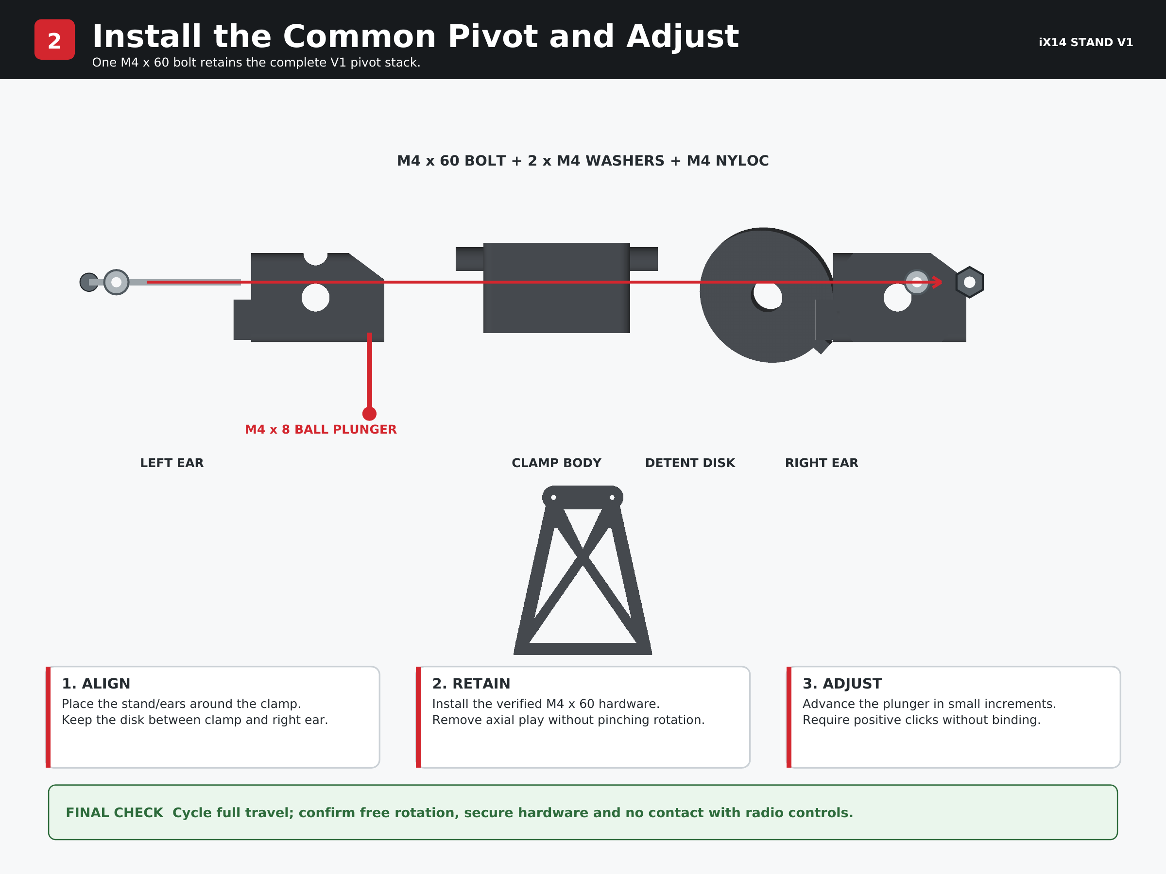
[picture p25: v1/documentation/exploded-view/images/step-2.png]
Stage 2: install the pivot hardware and adjust the stand


1. Identify the left ear by its half-round ball-plunger access relief and the right ear by its keyed detent-disk interface.
2. Attach each ear behind the corresponding upper stand hole using one M3 x 8 screw and M3 washer per side. The stand header and mounting holes belong at the top.
3. Seat the keyed detent disk fully on the right ear without forcing it.
4. Position the completed stand-and-ear assembly around the clamp body and align the common pivot bore.
5. Keep the detent disk between the right side of the clamp body and right ear, with its pockets facing the ball plunger.
6. Fit one M4 washer under the head of the verified M4 x 60 pivot bolt and pass the bolt through the complete pivot stack.
7. Fit the second M4 washer and M4 Nyloc nut on the threaded end.
8. Tighten only until axial play is removed. The stand must still rotate freely.

## 3. Install and adjust the ball plunger

1. Use the relief in the left ear to access the M4 insert in the clamp body.
2. Use something thin, such as an awl or straightened paper clip, to place a **small amount of removable, non-permanent threadlocker** (for example, blue Loctite) inside the receiving threads of the M4 insert. Keep the threadlocker off the surrounding plastic and out of the plunger mechanism.
3. Insert and thread the M4 x 8 spring-loaded ball plunger **ball end first** into the insert.
4. Advance the plunger a little at a time while repeatedly moving the stand between its fully folded and fully extended positions.
5. Stop when the ball engages the detent pockets solidly at each indexed position without making the pivot overly tight or difficult to move.
6. Cycle the stand through its full travel and confirm consistent engagement.

The correct setting is the point at which the detents feel deliberate and secure while the stand still moves smoothly. Do not use permanent threadlocker.

## Final inspection

- Clamp body and cap are seated evenly and cannot rotate on the handle
- Both M3 x 12 clamp screws are secure
- Both M3 x 8 stand screws have washers and are secure
- M4 x 60 pivot bolt has a washer at both ends and the Nyloc nut is secure
- Stand rotates freely without axial looseness
- Detent disk remains fully keyed to the right ear
- Ball plunger engages consistently without binding
- Stand supports the radio at the intended angle
- Stand folds without contacting the radio body, switches or controls

## Safety and maintenance

- This is a desk/simulator stand, not a replacement carrying handle.
- V1 occupies more of the handle area and has a taller stowed profile than V2.
- Inspect the printed parts, inserts and fasteners periodically for cracks, loosening or wear.
- Never force the stand beyond its designed range of motion.
- Review the repository's [`DISCLAIMER.md`](../../../DISCLAIMER.md) before printing or using the design.

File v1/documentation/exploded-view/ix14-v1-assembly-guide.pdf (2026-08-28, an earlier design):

# 1 Mount the Clamp to the Handle

The V1 clamp occupies the center section of the factory handle.

iX14 STAND V1

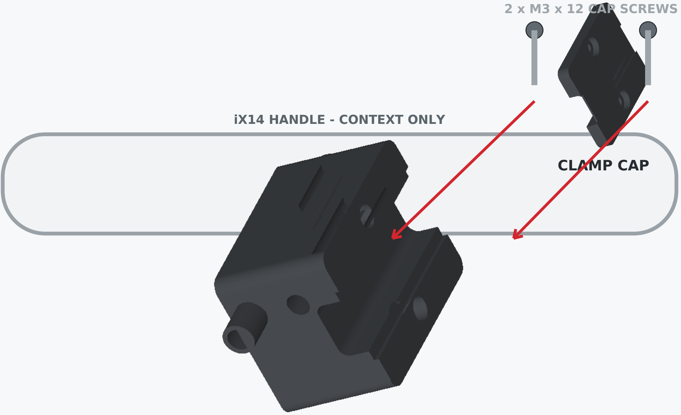
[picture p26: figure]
iX14 HANDLE - CONTEXT ONLY; CLAMP CAP; 2 x M3 x 12 CAP SCREWS

### CLAMP BODY

POSITION
Center the body around the handle.
Point the common pivot sleeve toward the rear. Fit the cap into the matching opening.

TIGHTEN EVENLY
Alternate between the two M3 x 12 screws. Stop when the clamp cannot rotate.
Washers are not required under the cap screws.

LEGACY NOTE V1 uses more handle space and has a taller stowed profile; V2 is recommended for new builds.

# 2 Install the Common Pivot and Adjust

One M4 x 60 bolt retains the complete V1 pivot stack.

iX14 STAND V1

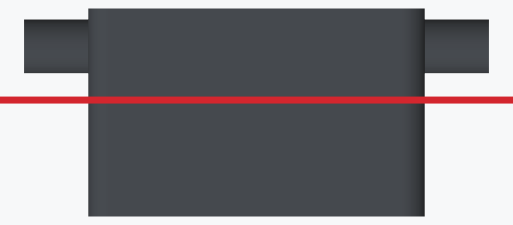
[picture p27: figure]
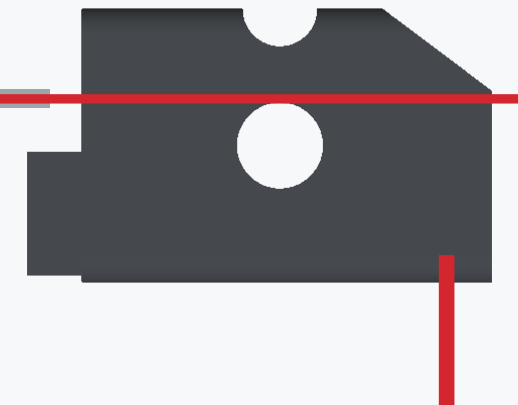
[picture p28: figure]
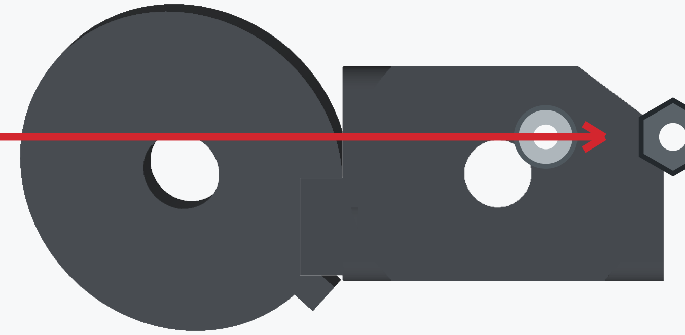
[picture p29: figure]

LEFT EAR | CLAMP BODY | DETENT DISK | RIGHT EAR

M4 x 60 BOLT + 2 x M4 WASHERS + M4 NYLOC

M4 x 8 BALL PLUNGER

### 1. ALIGN

Place the stand/ears around the clamp. Keep the disk between clamp and right ear.

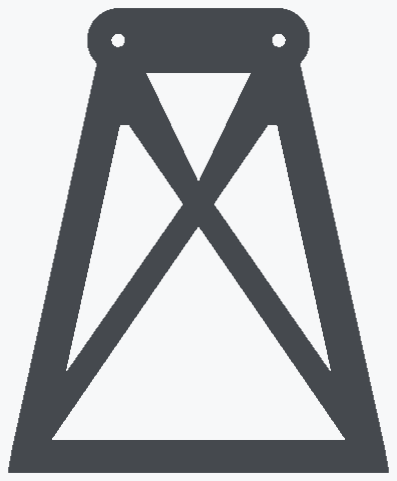
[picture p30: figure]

### 2. RETAIN

Install the verified M4 x 60 hardware. Remove axial play without pinching rotation.

### 3. ADJUST

Advance the plunger in small increments. Require positive clicks without binding.

FINAL CHECK Cycle full travel; confirm free rotation, secure hardware and no contact with radio controls.

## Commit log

2026-08-23 Reorg directories, add README.md & LICENSE
    [ix14_v1_radio_mount.3mf, ix14_v1_stand_painted_chamfer.3mf]
2026-08-28 Reorg some dirs and inital v2 file commits
    [ix14_v1_clamp_body.stl, ix14_v1_clamp_cap.stl, ix14_v1_detent.stl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]
2026-08-28 Edit updates
    [ix14_v2_left_case_cap.stl]
2026-08-28 Assembly instructions
2026-08-28 Updated to assembly instructions sub link paths
2026-08-28 v1 updates
    [ix14_v1_radio_mount.3mf, ix14_v1_stand_all_objects.3mf, ix14_v1_stand_painted_chamfer.3mf]
2026-08-28 Updated v1 3mf
    [ix14_v1_stand_all_objects.3mf]
2026-08-29 Add case fit images and update contact sheet
